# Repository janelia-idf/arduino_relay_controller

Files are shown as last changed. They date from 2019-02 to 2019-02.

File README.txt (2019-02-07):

========================
Arduino Relay Controller
========================

Arduino-based relay controller to control 24V solenoids, etc.

firmware
========

Contains the Arduino firmware files. See firmware/README.txt

host
====

Contains the code for controlling with a host computer.

python
------

See host/python/README.txt

pcb
===

Contains the arduino_relay_controller pcb Kicad and gerber files.

Author: Peter Polidoro

This program is free software: you can redistribute it and/or modify
it under the terms of the GNU Lesser General Public License as published by
the Free Software Foundation, either version 3 of the License, or
(at your option) any later version.

This program is distributed in the hope that it will be useful,
but WITHOUT ANY WARRANTY; without even the implied warranty of
MERCHANTABILITY or FITNESS FOR A PARTICULAR PURPOSE.  See the
GNU Lesser General Public License for more details.

You should have received a copy of the GNU Lesser General Public License
along with this program.  If not, see <http://www.gnu.org/licenses/>.

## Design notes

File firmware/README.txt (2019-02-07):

Arduino Relay Controller Device Firmware
----------------------------------------

Arduino firmware for the arduino_relay_controller device.

For see the INSTALL.txt for installation instructions.

arduino_relay_controller device firmware may be freely distributed and
modified in accordance with the License.

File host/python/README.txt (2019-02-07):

========================
arduino_relay_controller
========================

arduino_relay_controller is a python package to control the Arduino
relay controller over USB, using the python module, the command line, a
GUI, or a webpage using a webserver.

Install
-------

See INSTALL.txt

Python Module
-------------

Typical usage often looks like this::

    from arduino_relay_controller import ArduinoRelayController, ArduinoRelayControllers

    relay_controllers = ArduinoRelayControllers()
    device_count = len(relay_controllers)
    if device_count == 0:
        raise RuntimeError('No Arduino relay controllers detected, check connections.')
    valve_count = relay_controllers[0].valve_count
    mfc_count = relay_controllers[0].mfc_count

    o = ArduinoRelay_Controllers[0]
    o.setMfcFlowRate(mfc=1,percent_capacity=75)
    print o.getMfcFlowRateSetting(mfc=1)
    print o.getMfcFlowRateMeasure(mfc=0)
    o.setOdorValveOn(valve=4)
    o.setOdorValvesOff()

Author: Peter Polidoro

This program is free software: you can redistribute it and/or modify
it under the terms of the GNU Lesser General Public License as published by
the Free Software Foundation, either version 3 of the License, or
(at your option) any later version.

This program is distributed in the hope that it will be useful,
but WITHOUT ANY WARRANTY; without even the implied warranty of
MERCHANTABILITY or FITNESS FOR A PARTICULAR PURPOSE.  See the
GNU Lesser General Public License for more details.

You should have received a copy of the GNU Lesser General Public License
along with this program.  If not, see <http://www.gnu.org/licenses/>.

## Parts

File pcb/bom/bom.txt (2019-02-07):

-*- mode:org -*-

# Opt101.lst
| ref     | value                    |
|---------+--------------------------|
| C1      | 0.1uF                    |
| C2      | 0.1uF                    |
| C3      | 10uF                     |
| C4      | 10uF                     |
| C5      | 2.2uF                    |
| C6      | 2.2uF                    |
| C7      | 0.1uF                    |
| D1      | LED                      |
| D2      | LED                      |
| D3      | LED                      |
| D4      | LED                      |
| D5      | LED                      |
| D6      | LED                      |
| D7      | LED                      |
| D8      | LED                      |
| D9      | LED                      |
| K1      | CONN_3                   |
| K2      | CONN_3                   |
| K3      | CONN_3                   |
| K4      | CONN_3                   |
| P1      | CONN_POWER               |
| P2      | CONN_2                   |
| P3      | CONN_2                   |
| P4      | CONN_2                   |
| P5      | CONN_2                   |
| P6      | CONN_2                   |
| P7      | CONN_2                   |
| P8      | CONN_2                   |
| P9      | CONN_2                   |
| R1      | 1.96k                    |
| RP1     | R_PACK8_2.2k             |
| SHIELD1 | ARDUINO_MEGA_SHIELD_FULL |
| U1      | BAT54TW                  |
| U2      | BAT54TW                  |
| U3      | BAT54TW                  |
| U4      | TLE7232                  |

# Bill of Materials
| ! | part    | description                      | vendor      | part number       | quantity |   cost |
|---+---------+----------------------------------+-------------+-------------------+----------+--------|
|   | PCB     | arduino_relay_control            | pcbuniverse |                   |        1 |   1.00 |
|   | C1-2,7  | CAP CER 0.1UF 50V 10% X7R 1210   | digikey     | 478-3586-1-ND     |        3 |   0.39 |
|   | C3-4    | CAP CER 10UF 50V 10% X7S 1210    | digikey     | 445-4536-1-ND     |        2 |   1.24 |
|   | C5-6    | CAP TANT 2.2UF 35V 10% 1210      | digikey     | 478-2414-1-ND     |        2 |   1.25 |
|   | D1-9    | LED GREEN CLEAR 0805 SMD         | digikey     | 160-1179-1-ND     |        9 |   0.35 |
|   | K1-4    | CONN HEADER 3POS .100 VERT GOLD  | digikey     | WM4801-ND         |        4 |   0.96 |
|   | P1      | CONN PWR JACK DC 2.1X5.5 8A T/H  | digikey     | CP-063AH-ND       |        1 |   1.78 |
|   | P1      | TRANSFORMER DESK TOP 24V 60W     | digikey     | T1208-P5P-ND      |        1 |  26.98 |
|   | P2-9    | CONN HEADER 2POS .100 VERT GOLD  | digikey     | WM4800-ND         |        8 |   0.88 |
|   | R1      | RES 1.96K OHM 1/2W 1% 1210 SMD   | digikey     | 541-1.96KAACT-ND  |        1 |   2.89 |
|   | RP1     | RES ARRAY 2.2K OHM 8 RES 16SOIC  | digikey     | 767-163-R2.2KP-ND |        1 |   1.30 |
|   | SHIELD1 | BOARD MCU MEGA2560               | digikey     | 1050-1018-ND      |        1 |  51.91 |
|   | SHIELD1 | CONN HEADER 50POS .100" SGL GOLD | digikey     | SAM1031-50-ND     |        4 |   3.33 |
|   | U1-3    | DIODE SCHOTTKY 30V 200MA SOT363  | digikey     | BAT54TW-FDICT-ND  |        3 |   0.49 |
|   | U4      | IC SPI DRIVER RELAY CTRL PDSO-24 | digikey     | TLE7232GCT-ND     |        1 |   4.18 |
|---+---------+----------------------------------+-------------+-------------------+----------+--------|
| # | total   |                                  |             |                   |          | 125.01 |
#+TBLFM: @17$7=(@I$quantity..@II$quantity)*(@I$cost..@II$cost);%.2f;N

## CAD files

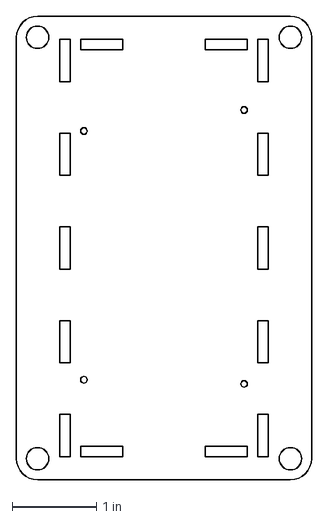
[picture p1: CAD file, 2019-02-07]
enclosure/arduino_enclosure.25in.dxf
3.50 x 5.50 in

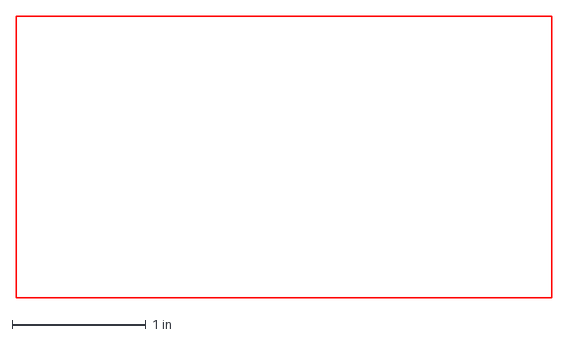
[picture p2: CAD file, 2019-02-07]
pcb/v1/dxf/arduino_relay_control-SilkS_Back.dxf
4.00 x 2.10 in

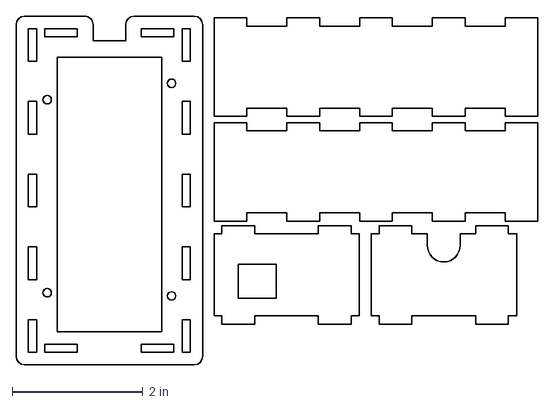
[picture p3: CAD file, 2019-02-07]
enclosure/arduino_enclosure.125in.dxf
7.97 x 5.32 in

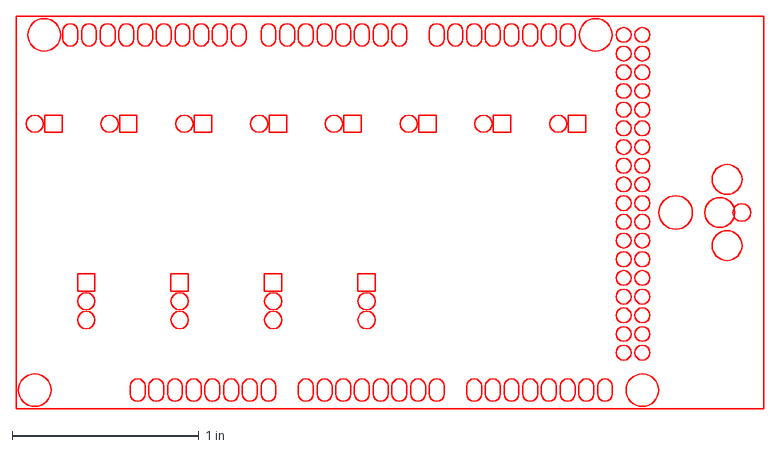
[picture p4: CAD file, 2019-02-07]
pcb/v1/dxf/arduino_relay_control-Mask_Back.dxf
4.00 x 2.10 in

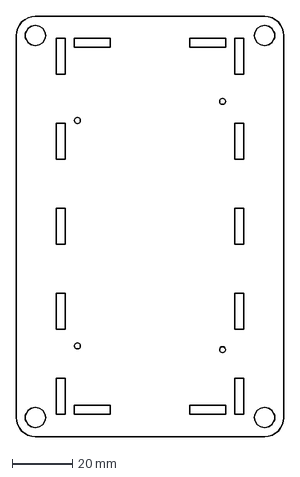
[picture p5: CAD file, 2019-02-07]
enclosure/arduino_enclosure_6mm.dxf
88.9 x 139.7 mm

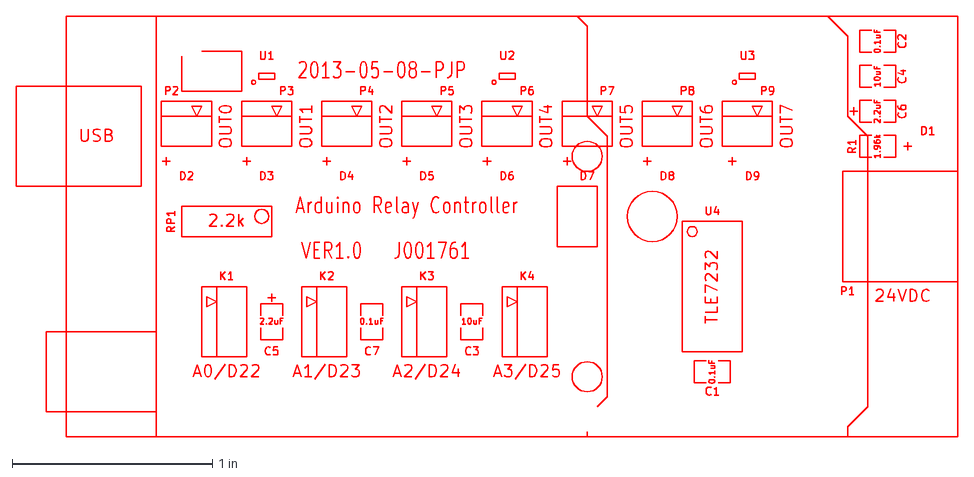
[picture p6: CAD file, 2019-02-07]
pcb/v1/dxf/arduino_relay_control-SilkS_Front.dxf
4.70 x 2.10 in

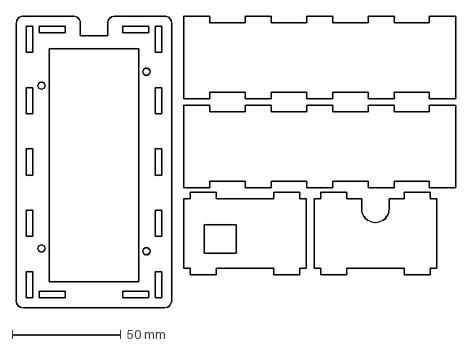
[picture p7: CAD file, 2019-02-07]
enclosure/arduino_enclosure_3mm.dxf
202.0 x 134.0 mm

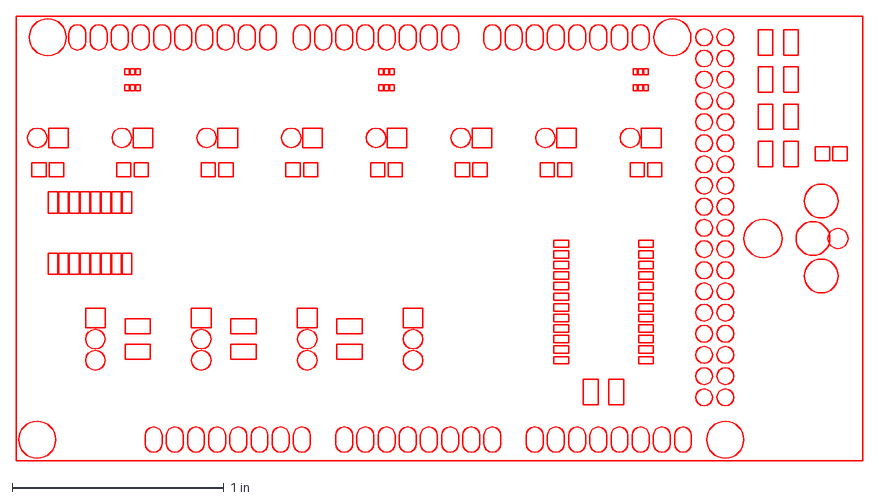
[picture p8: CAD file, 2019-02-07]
pcb/v1/dxf/arduino_relay_control-Mask_Front.dxf
4.00 x 2.10 in

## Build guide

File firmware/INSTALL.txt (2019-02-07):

Firmware installation instructions
-----------------------------------

Requirements:

The following libraries should be placed in the arduino sketchbook libraries 
directory.

* Streaming         https://bitbucket.org/peterpolidoro/arduino_libs/src
* SerialReceiver    https://bitbucket.org/peterpolidoro/arduino_libs/src 
* DictPrinter       https://bitbucket.org/peterpolidoro/arduino_libs/src 
* Tle7232g          https://bitbucket.org/peterpolidoro/arduino_libs/src 

Build and upload the firmware using the Arduino IDE.

see http://arduino.cc/en/Guide/Environment for instructions on using the IDE.

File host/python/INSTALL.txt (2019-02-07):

arduino_relay_controller installation instructions
--------------------------------------------------

* Create a new virtual environment if necessary::

    virtualenv --system-site-packages ~/virtualenvs/arduino_relay_controller

* Activate a virtual environment::

    source ~/virualenvs/arduino_relay_controller/bin/activate

* Install dependencies::

    pip install flask --upgrade
    pip install flask-sijax --upgrade

* Clone bitbucket mercurial repositories:: 
  
    mkdir ~/arduino_relay_controller
    cd ~/arduino_relay_controller
    hg clone https://bitbucket.org/peterpolidoro/python_libs/
    hg clone https://bitbucket.org/peterpolidoro/arduino_relay_controller/

* Install python packages::

    cd ~/arduino_relay_controller/python_libs/arduino_device
    python setup.py install
    cd ~/arduino_relay_controller/arduino_relay_controller/host/python
    python setup.py install

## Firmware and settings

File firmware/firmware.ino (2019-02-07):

#include <SPI.h>
#include <Streaming.h>
#include <EEPROM.h>
#include <util/atomic.h>

#include "SerialReceiver.h"
#include "DictPrinter.h"
#include "Tle7232g.h"
#include "TimeTriggeredScheduler.h"

#include "constants.h"
#include "SystemState.h"
#include "MessageHandler.h"

void setup() {
    Serial.begin(constants::baudrate);
    systemState.initialize();
}

void loop() { 
    messageHandler.processMsg(); 
}

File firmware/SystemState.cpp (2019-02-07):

#if defined(ARDUINO) && ARDUINO >= 100
#include "Arduino.h"
#else
#include "WProgram.h"
#endif
#include "string.h"
#include "SystemState.h"

SystemState::SystemState() {
  setErrMsg("");
}

void SystemState::setErrMsg(char *msg) {
  strncpy(errMsg,msg,SYS_ERR_BUF_SZ);
}

void SystemState::initialize() {
  relayDriver = TLE7232G(constants::relayDriverCsPin,constants::relayDriverInPin);

  // Initialize SPI:
  SPI.setDataMode(SPI_MODE1);
  SPI.setClockDivider(SPI_CLOCK_DIV4);
  SPI.setBitOrder(MSBFIRST);
  SPI.begin();

  relayDriver.init(1);
  setAllRelaysOff();

  tts.init();

  for (int relay; relay < constants::relayCount; relay++) {
    relayBlinkTasks[relay].onTaskId = -1;
    relayBlinkTasks[relay].offTaskId = -1;
  }

  for (int digital_output; digital_output < constants::digitalOutputCount; digital_output++) {
    pinMode(constants::digitalOutputPins[digital_output], OUTPUT);
    digitalWrite(constants::digitalOutputPins[digital_output], LOW);
    digitalOutputStates[digital_output] = LOW;
  }

  for (int digital_input; digital_input < constants::digitalInputCount; digital_input++) {
    pinMode(constants::digitalInputPins[digital_input], INPUT);
    digitalWrite(constants::digitalInputPins[digital_input], HIGH);
  }

}

bool SystemState::setRelays(uint32_t relays) {
  relayDriver.setChannels(relays);
  return true;
}

bool SystemState::setRelayOn(int relay) {
  relayDriver.setChannelOn(relay);
  return true;
}

bool SystemState::setRelayOff(int relay) {
  relayDriver.setChannelOff(relay);
  return true;
}

bool SystemState::setAllRelaysOn() {
  uint32_t relays = 0;
  relays = ~relays;
  setRelays(relays);
  return true;
}

bool SystemState::setAllRelaysOff() {
  uint32_t relays = 0;
  setRelays(relays);
  return true;
}

bool SystemState::startRelayBlink(int relay, long period, int duty_cycle, long count=-1) {
  stopRelayBlink(relay);
  if ((0 < duty_cycle) && (duty_cycle < 100)) {
    int onTaskId = (int)tts.addTaskUsingDelay(100,inlineSetRelayOn,relay,period,count,false);
    int offTaskId = (int)tts.addTaskUsingOffset((uint8_t)onTaskId,(period*duty_cycle)/100,inlineSetRelayOff,relay,period,count,false);

    // Only save continuous blink patterns. Let patterns with count
    // expire naturally. This means multiple blink patterns could
    // overlap until count expires and that finite blink patterns
    // cannot be stopped unless all tasks are removed.

    if (count < 0) {
      relayBlinkTasks[relay].onTaskId = onTaskId;
      relayBlinkTasks[relay].offTaskId = offTaskId;
    }
  } else if (100 <= duty_cycle) {
    setRelayOn(relay);
  }
  return true;
}

bool SystemState::stopRelayBlink(int relay) {
  int onTaskId = relayBlinkTasks[relay].onTaskId;
  int offTaskId = relayBlinkTasks[relay].offTaskId;
  if (0 <= onTaskId) {
    tts.removeTask((uint8_t)onTaskId);
    relayBlinkTasks[relay].onTaskId = -1;
  }
  if (0 <= offTaskId) {
    tts.removeTask((uint8_t)offTaskId);
    relayBlinkTasks[relay].offTaskId = -1;
  }
  setRelayOff(relay);
  return true;
}

bool SystemState::stopAllRelaysBlink() {
  for (uint8_t relay; relay < constants::relayCount; relay++) {
    stopRelayBlink(relay);
  }
  return true;
}

bool SystemState::addPulseCentered(int relay, long delay, long duration) {
  long rising = delay - duration/2;
  if (rising < 0) {
    rising = 0;
  }
  int onTaskId = (int)tts.addTaskUsingDelay(rising,inlineSetRelayOn,relay,-1,-1,false);
  tts.addTaskUsingOffset((uint8_t)onTaskId,duration,inlineSetRelayOff,relay,-1,-1,false);
  return true;
}

bool SystemState::setDigitalOutputHigh(int digital_output) {
  digitalWrite(constants::digitalOutputPins[digital_output], HIGH);
  digitalOutputStates[digital_output] = HIGH;
  return true;
}

bool SystemState::setDigitalOutputLow(int digital_output) {
  digitalWrite(constants::digitalOutputPins[digital_output], LOW);
  digitalOutputStates[digital_output] = LOW;
  return true;
}

bool SystemState::toggleDigitalOutput(int digital_output) {
  if (digitalOutputStates[digital_output] == LOW) {
    setDigitalOutputHigh(digital_output);
  } else {
    setDigitalOutputLow(digital_output);
  }
  return true;
}

bool SystemState::pulseDigitalOutput(int digital_output, long duration) {
  int onTaskId = (int)tts.addTaskUsingDelay(0,inlineSetDigitalOutputHigh,digital_output,-1,-1,false);
  tts.addTaskUsingOffset((uint8_t)onTaskId,duration,inlineSetDigitalOutputLow,digital_output,-1,-1,false);
  return true;
}

int SystemState::getDigitalInput(int digital_input) {
  return digitalRead(constants::digitalInputPins[digital_input]);
}

bool SystemState::removeAllTasks() {
  return tts.removeAllTasks();
}

uint32_t SystemState::getTime() {
  return tts.ms();
}

bool SystemState::setTime(uint32_t time=0) {
  tts.setTime(time);
  return true;
}

bool SystemState::getTaskDetails(uint8_t taskId, uint32_t& time, int& arg, long& period, long& count, bool& free, bool& enabled) {
  tts.getTaskDetails(taskId, time, arg, period, count, free, enabled);
  return true;
}

SystemState systemState;
